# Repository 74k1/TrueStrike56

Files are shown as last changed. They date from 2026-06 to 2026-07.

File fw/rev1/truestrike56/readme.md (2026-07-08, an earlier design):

# TrueStrike56

TrueStrike56 is a columnar staggered unibody split Hall effect keyboard designed to maximize performance and minimize finger fatigue.

Hall effect part of this firmware code is a derivative work of Cipulot's code.
OLED display part of this firmware code is a derivative work of Dasky's code.

* Keyboard Maintainer: [byungyoonc](https://github.com/byungyoonc)
* Hardware Supported: RP2040 development boards with Pro Micro pin layout
* Hardware Availability: https://github.com/byungyoonc/TrueStrike56

Make example for this keyboard (after setting up your build environment):

    make truestrike56:default

Flashing example for this keyboard:

    make truestrike56:default:flash
    
    OR
    
    Copy the built `uf2` firmware file into `RPI-RP2` drive when the controller is in the bootloader mode

See the [build environment setup](https://docs.qmk.fm/#/getting_started_build_tools) and the [make instructions](https://docs.qmk.fm/#/getting_started_make_guide) for more information. Brand new to QMK? Start with our [Complete Newbs Guide](https://docs.qmk.fm/#/newbs).

## Bootloader

Enter the bootloader in 2 ways:

* **Physical reset button**: Quickly double-press the button on the back of the PCB
* **Keycode in layout**: Press the key mapped to `QK_BOOT` if it is available

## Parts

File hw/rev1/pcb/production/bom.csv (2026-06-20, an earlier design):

Designator | Footprint | Quantity | Value | LCSC Part #
C1, C10, C11, C12, C13, C14, C15, C16, C17, C18, C19, C2, C20, C21, C22, C23, C24, C25, C26, C27, C28, C29, C3, C30, C31, C32, C33, C34, C35, C36, C37, C38, C39, C4, C40, C41, C42, C43, C44, C45, C46, C47, C48, C49, C5, C50, C51, C52, C53, C54, C55, C56, C57, C58, C59, C6, C60, C61, C62, C63, C64, C65, C66, C67, C68, C69, C7, C70, C71, C72, C73, C74, C8, C9 | 0805 | 74 | 1uF | C28233
D1, D13, D14, D15, D16, D17, D18, D2, D3, D33, D34, D35, D36, D37, D38, D4, D45, D46, D47, D48, D49, D5, D50, D6 | SK6812MINI-E_nusumi | 24 | SK6812MINI-E | C5149201
D10, D11, D12, D19, D20, D21, D22, D23, D24, D25, D26, D27, D28, D29, D30, D31, D32, D39, D40, D41, D42, D43, D44, D51, D52, D53, D54, D55, D56, D7, D8, D9 | SK6812MINI-E_nusumi_Rotated | 32 | SK6812MINI-E | C5149201
S1, S10, S11, S12, S13, S14, S15, S16, S17, S18, S19, S2, S20, S21, S22, S23, S24, S25, S26, S27, S28, S29, S3, S30, S31, S32, S33, S34, S35, S36, S37, S38, S39, S4, S40, S41, S42, S43, S44, S45, S46, S47, S48, S49, S5, S50, S51, S54, S55, S56, S6, S7, S8, S9 | HE-Switch-1U | 54 | SLSS49E | C126669
S52, S53 | HE-Switch-1.5U | 2 | SLSS49E | C126669
SW1 | SW_Push_1P1T_XKB_TS-1187A | 1 | SW_Push | C318884
U10 | SOIC-16_3.9x9.9mm_P1.27mm | 1 | 4053 | C5647
U2, U3, U4, U5, U6, U7, U8 | SOIC-16_3.9x9.9mm_P1.27mm | 7 | 74HC4051 | C85220
U9 | SOIC-14_3.9x8.7mm_P1.27mm | 1 | 74AHCT125 | C155176

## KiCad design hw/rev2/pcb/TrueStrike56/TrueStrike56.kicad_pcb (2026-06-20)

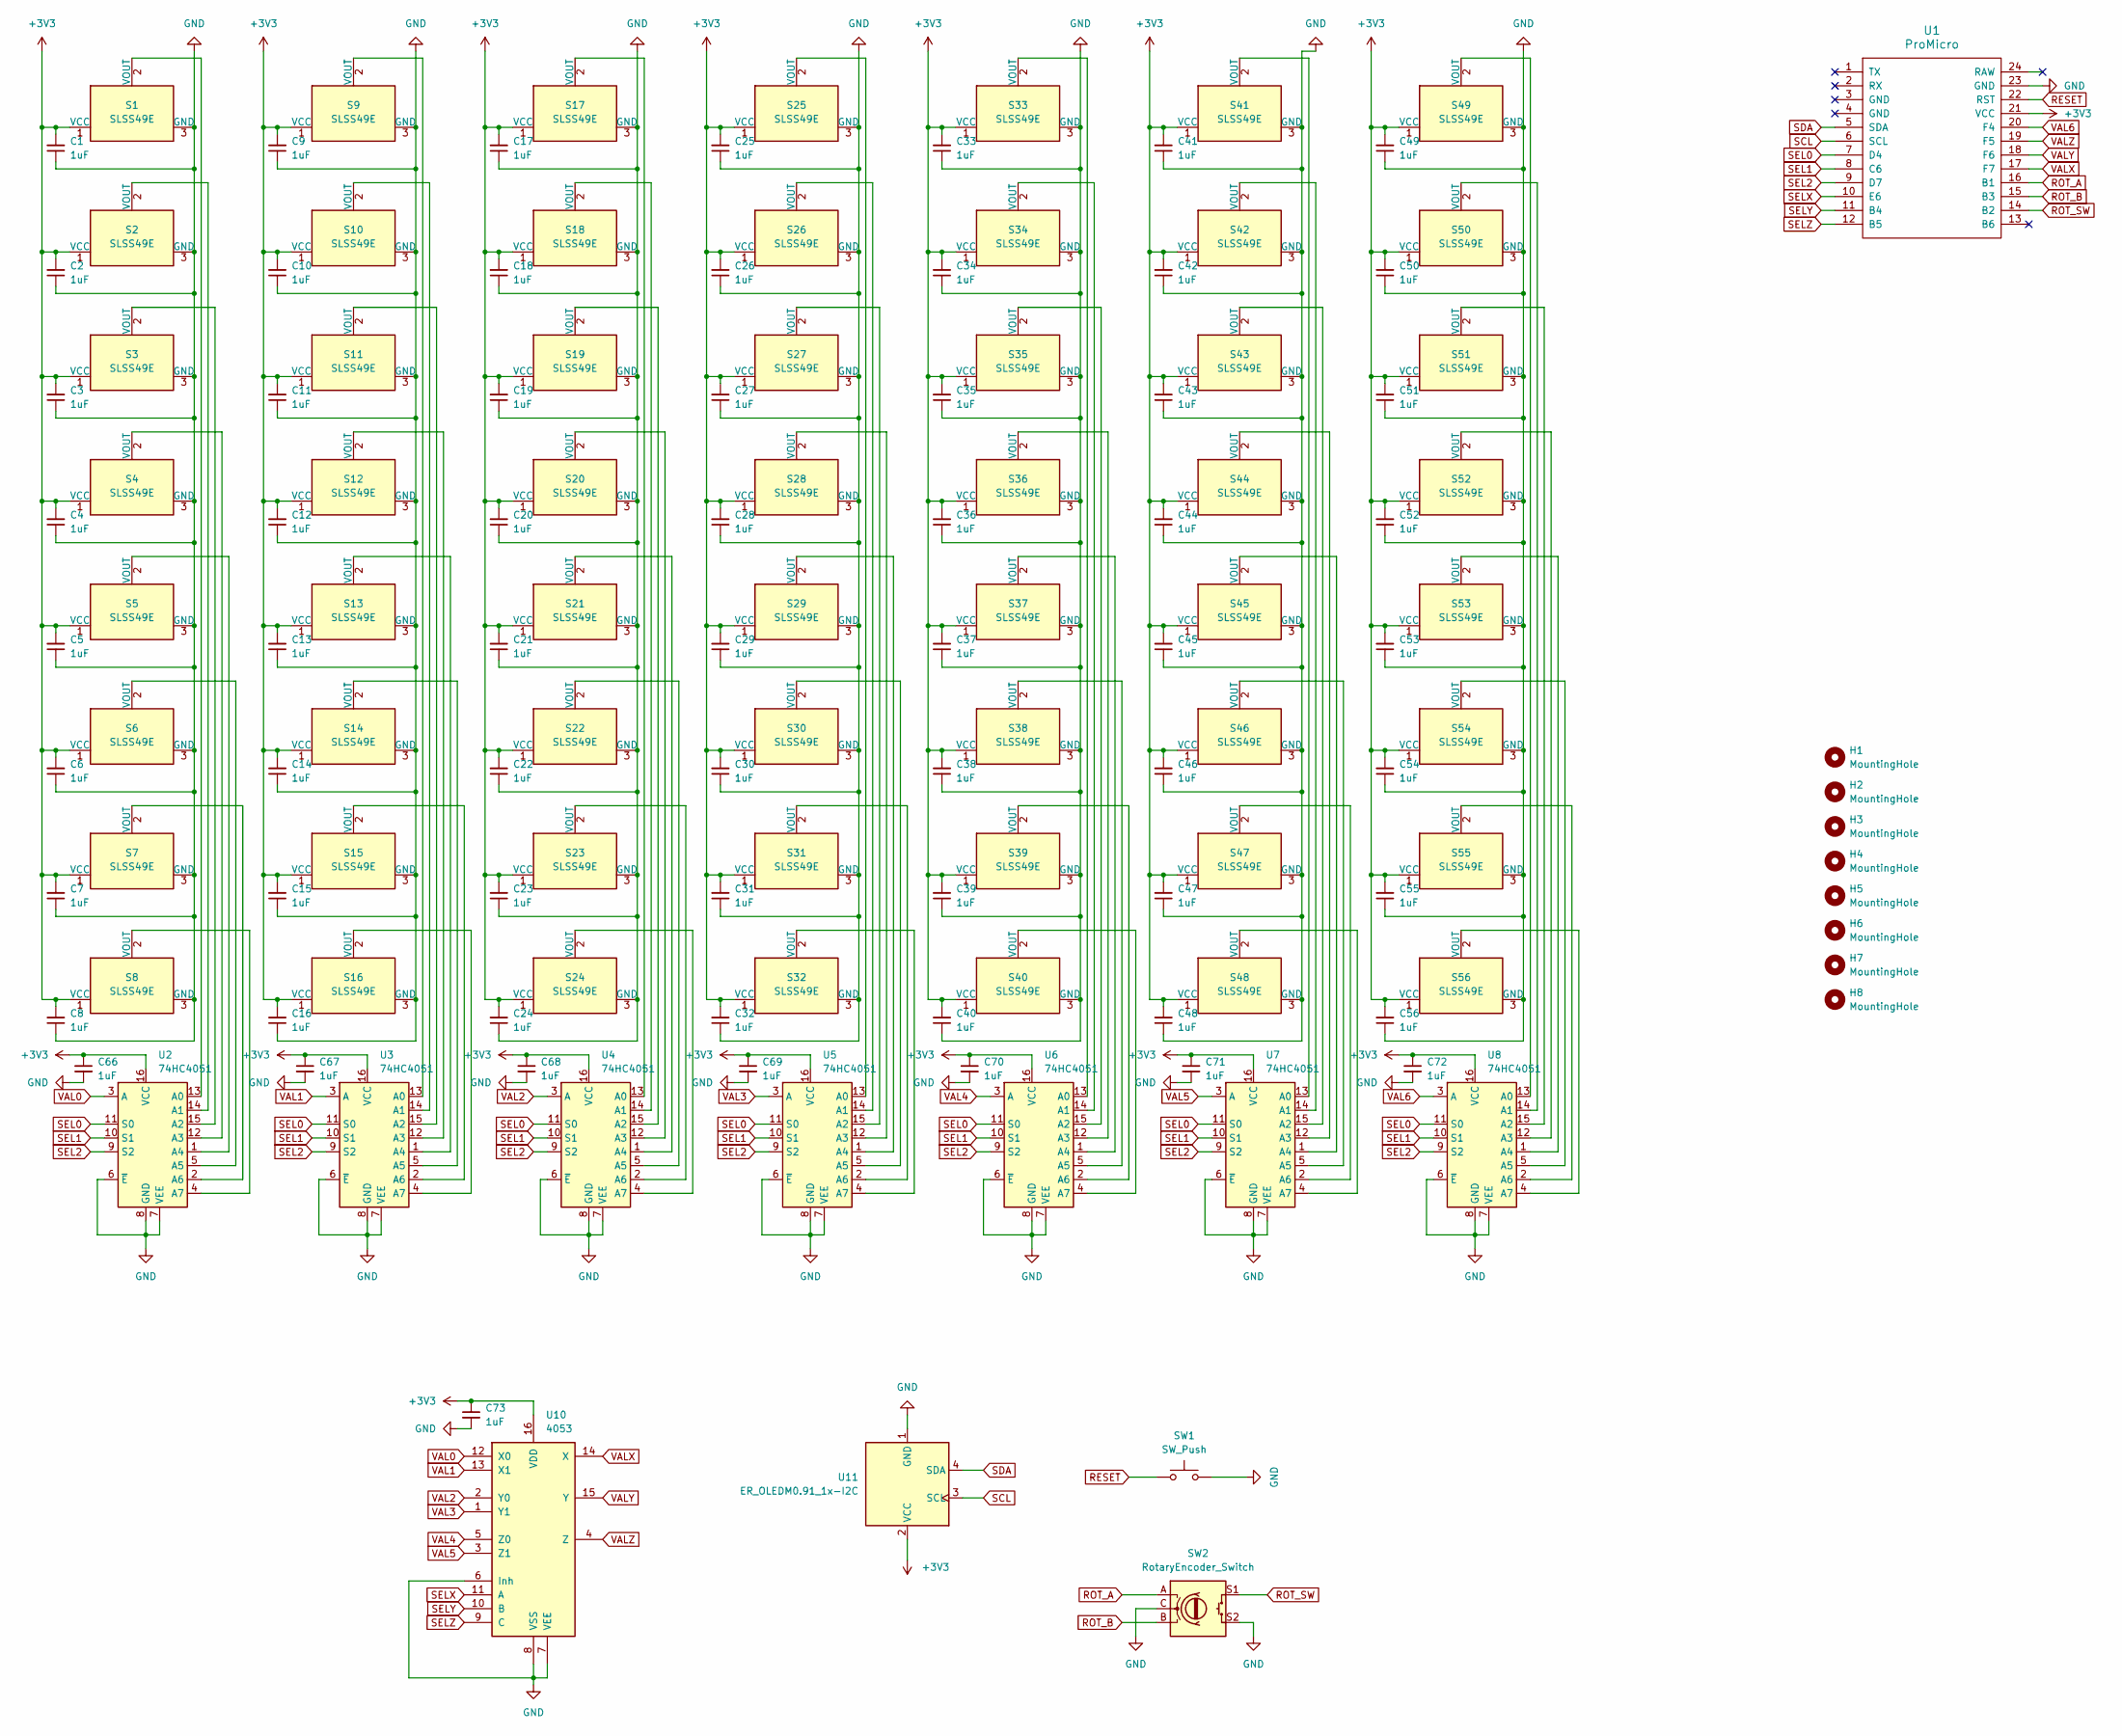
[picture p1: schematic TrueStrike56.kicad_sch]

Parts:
C1, C2, C3, C4, C5, C6, C7, C8, C9, C10, C11, C12, C13, C14, C15, C16, C17, C18, C19, C20, C21, C22, C23, C24, C25, C26, C27, C28, C29, C30, C31, C32, C33, C34, C35, C36, C37, C38, C39, C40, C41, C42, C43, C44, C45, C46, C47, C48, C49, C50, C51, C52, C53, C54, C55, C56, C66, C67, C68, C69, C70, C71, C72, C73: 1uF; C_0805_2012Metric_Pad1.18x1.45mm_HandSolder; LCSC Part # C28233
H1, H2, H3, H4, H5, H6, H7, H8: MountingHole; MountingHole_3.5mm
S1, S2, S3, S4, S5, S6, S7, S8, S9, S10, S11, S12, S13, S14, S15, S16, S17, S18, S19, S20, S21, S22, S23, S24, S25, S26, S27, S28, S29, S30, S31, S32, S33, S34, S35, S36, S37, S38, S39, S40, S41, S42, S43, S44, S45, S46, S47, S48, S49, S50, S51, S54, S55, S56: SLSS49E; HE-Switch-1U; LCSC Part # C126669
S52, S53: SLSS49E; HE-Switch-1.5U; LCSC Part # C126669
SW1: SW_Push; SW_Push_1P1T_XKB_TS-1187A; LCSC Part # C318884
SW2: RotaryEncoder_Switch; RollerEncoder_Panasonic_EVQWGD001
U1: ProMicro
U2, U3, U4, U5, U6, U7, U8: 74HC4051; SOIC-16_3.9x9.9mm_P1.27mm; LCSC Part # C85220
U10: 4053; SOIC-16_3.9x9.9mm_P1.27mm; LCSC Part # C5647
U11: ER_OLEDM0.91_1x-I2C

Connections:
+3V3: C1.2, C2.2, C3.2, C4.2, C5.2, C6.2, C7.2, C8.2, C9.2, C10.2, C11.2, C12.2, C13.2, C14.2, C15.2, C16.2, C17.2, C18.2, C19.2, C20.2, C21.2, C22.2, C23.2, C24.2, C25.2, C26.2, C27.2, C28.2, C29.2, C30.2, C31.2, C32.2, C33.2, C34.2, C35.2, C36.2, C37.2, C38.2, C39.2, C40.2, C41.2, C42.2, C43.2, C44.2, C45.2, C46.2, C47.2, C48.2, C49.2, C50.2, C51.2, C52.2, C53.2, C54.2, C55.2, C56.2, C66.1, C67.1, C68.1, C69.1, C70.1, C71.1, C72.1, C73.1, S1.1 (VCC), S2.1 (VCC), S3.1 (VCC), S4.1 (VCC), S5.1 (VCC), S6.1 (VCC), S7.1 (VCC), S8.1 (VCC), S9.1 (VCC), S10.1 (VCC), S11.1 (VCC), S12.1 (VCC), S13.1 (VCC), S14.1 (VCC), S15.1 (VCC), S16.1 (VCC), S17.1 (VCC), S18.1 (VCC), S19.1 (VCC), S20.1 (VCC), S21.1 (VCC), S22.1 (VCC), S23.1 (VCC), S24.1 (VCC), S25.1 (VCC), S26.1 (VCC), S27.1 (VCC), S28.1 (VCC), S29.1 (VCC), S30.1 (VCC), S31.1 (VCC), S32.1 (VCC), S33.1 (VCC), S34.1 (VCC), S35.1 (VCC), S36.1 (VCC), S37.1 (VCC), S38.1 (VCC), S39.1 (VCC), S40.1 (VCC), S41.1 (VCC), S42.1 (VCC), S43.1 (VCC), S44.1 (VCC), S45.1 (VCC), S46.1 (VCC), S47.1 (VCC), S48.1 (VCC), S49.1 (VCC), S50.1 (VCC), S51.1 (VCC), S52.1 (VCC), S53.1 (VCC), S54.1 (VCC), S55.1 (VCC), S56.1 (VCC), U1.21 (VCC), U2.16 (VCC), U3.16 (VCC), U4.16 (VCC), U5.16 (VCC), U6.16 (VCC), U7.16 (VCC), U8.16 (VCC), U10.16 (VDD), U11.2 (VCC)
GND: C1.1, C2.1, C3.1, C4.1, C5.1, C6.1, C7.1, C8.1, C9.1, C10.1, C11.1, C12.1, C13.1, C14.1, C15.1, C16.1, C17.1, C18.1, C19.1, C20.1, C21.1, C22.1, C23.1, C24.1, C25.1, C26.1, C27.1, C28.1, C29.1, C30.1, C31.1, C32.1, C33.1, C34.1, C35.1, C36.1, C37.1, C38.1, C39.1, C40.1, C41.1, C42.1, C43.1, C44.1, C45.1, C46.1, C47.1, C48.1, C49.1, C50.1, C51.1, C52.1, C53.1, C54.1, C55.1, C56.1, C66.2, C67.2, C68.2, C69.2, C70.2, C71.2, C72.2, C73.2, S1.3 (GND), S2.3 (GND), S3.3 (GND), S4.3 (GND), S5.3 (GND), S6.3 (GND), S7.3 (GND), S8.3 (GND), S9.3 (GND), S10.3 (GND), S11.3 (GND), S12.3 (GND), S13.3 (GND), S14.3 (GND), S15.3 (GND), S16.3 (GND), S17.3 (GND), S18.3 (GND), S19.3 (GND), S20.3 (GND), S21.3 (GND), S22.3 (GND), S23.3 (GND), S24.3 (GND), S25.3 (GND), S26.3 (GND), S27.3 (GND), S28.3 (GND), S29.3 (GND), S30.3 (GND), S31.3 (GND), S32.3 (GND), S33.3 (GND), S34.3 (GND), S35.3 (GND), S36.3 (GND), S37.3 (GND), S38.3 (GND), S39.3 (GND), S40.3 (GND), S41.3 (GND), S42.3 (GND), S43.3 (GND), S44.3 (GND), S45.3 (GND), S46.3 (GND), S47.3 (GND), S48.3 (GND), S49.3 (GND), S50.3 (GND), S51.3 (GND), S52.3 (GND), S53.3 (GND), S54.3 (GND), S55.3 (GND), S56.3 (GND), SW1.2, SW2.C, SW2.S2, U1.23 (GND), U2.6 (~E), U2.7 (VEE), U2.8 (GND), U3.6 (~E), U3.7 (VEE), U3.8 (GND), U4.6 (~E), U4.7 (VEE), U4.8 (GND), U5.6 (~E), U5.7 (VEE), U5.8 (GND), U6.6 (~E), U6.7 (VEE), U6.8 (GND), U7.6 (~E), U7.7 (VEE), U7.8 (GND), U8.6 (~E), U8.7 (VEE), U8.8 (GND), U10.6 (Inh), U10.7 (VEE), U10.8 (VSS), U11.1 (GND)
unnamed: S1.2 (VOUT), U2.13 (A0)
unnamed: S2.2 (VOUT), U2.14 (A1)
unnamed: S3.2 (VOUT), U2.15 (A2)
unnamed: S4.2 (VOUT), U2.12 (A3)
unnamed: S5.2 (VOUT), U2.1 (A4)
unnamed: S6.2 (VOUT), U2.5 (A5)
unnamed: S7.2 (VOUT), U2.2 (A6)
unnamed: S8.2 (VOUT), U2.4 (A7)
unnamed: S9.2 (VOUT), U3.13 (A0)
unnamed: S10.2 (VOUT), U3.14 (A1)
unnamed: S11.2 (VOUT), U3.15 (A2)
unnamed: S12.2 (VOUT), U3.12 (A3)
unnamed: S13.2 (VOUT), U3.1 (A4)
unnamed: S14.2 (VOUT), U3.5 (A5)
unnamed: S15.2 (VOUT), U3.2 (A6)
unnamed: S16.2 (VOUT), U3.4 (A7)
unnamed: S17.2 (VOUT), U4.13 (A0)
unnamed: S18.2 (VOUT), U4.14 (A1)
unnamed: S19.2 (VOUT), U4.15 (A2)
unnamed: S20.2 (VOUT), U4.12 (A3)
unnamed: S21.2 (VOUT), U4.1 (A4)
unnamed: S22.2 (VOUT), U4.5 (A5)
unnamed: S23.2 (VOUT), U4.2 (A6)
unnamed: S24.2 (VOUT), U4.4 (A7)
unnamed: S25.2 (VOUT), U5.13 (A0)
unnamed: S26.2 (VOUT), U5.14 (A1)
unnamed: S27.2 (VOUT), U5.15 (A2)
unnamed: S28.2 (VOUT), U5.12 (A3)
unnamed: S29.2 (VOUT), U5.1 (A4)
unnamed: S30.2 (VOUT), U5.5 (A5)
unnamed: S31.2 (VOUT), U5.2 (A6)
unnamed: S32.2 (VOUT), U5.4 (A7)
unnamed: S33.2 (VOUT), U6.13 (A0)
unnamed: S34.2 (VOUT), U6.14 (A1)
unnamed: S35.2 (VOUT), U6.15 (A2)
unnamed: S36.2 (VOUT), U6.12 (A3)
unnamed: S37.2 (VOUT), U6.1 (A4)
unnamed: S38.2 (VOUT), U6.5 (A5)
unnamed: S39.2 (VOUT), U6.2 (A6)
unnamed: S40.2 (VOUT), U6.4 (A7)
unnamed: S41.2 (VOUT), U7.13 (A0)
unnamed: S42.2 (VOUT), U7.14 (A1)
unnamed: S43.2 (VOUT), U7.15 (A2)
unnamed: S44.2 (VOUT), U7.12 (A3)
unnamed: S45.2 (VOUT), U7.1 (A4)
unnamed: S46.2 (VOUT), U7.5 (A5)
unnamed: S47.2 (VOUT), U7.2 (A6)
unnamed: S48.2 (VOUT), U7.4 (A7)
unnamed: S49.2 (VOUT), U8.13 (A0)
unnamed: S50.2 (VOUT), U8.14 (A1)
unnamed: S51.2 (VOUT), U8.15 (A2)
unnamed: S52.2 (VOUT), U8.12 (A3)
unnamed: S53.2 (VOUT), U8.1 (A4)
unnamed: S54.2 (VOUT), U8.5 (A5)
unnamed: S55.2 (VOUT), U8.2 (A6)
unnamed: S56.2 (VOUT), U8.4 (A7)
RESET: SW1.1, U1.22 (RST)
ROT_A: SW2.A, U1.16 (B1)
ROT_B: SW2.B, U1.15 (B3)
ROT_SW: SW2.S1, U1.14 (B2)
SCL: U1.6 (SCL), U11.3 (SCL)
SDA: U1.5 (SDA), U11.4 (SDA)
SEL0: U1.7 (D4), U2.11 (S0), U3.11 (S0), U4.11 (S0), U5.11 (S0), U6.11 (S0), U7.11 (S0), U8.11 (S0)
SEL1: U1.8 (C6), U2.10 (S1), U3.10 (S1), U4.10 (S1), U5.10 (S1), U6.10 (S1), U7.10 (S1), U8.10 (S1)
SEL2: U1.9 (D7), U2.9 (S2), U3.9 (S2), U4.9 (S2), U5.9 (S2), U6.9 (S2), U7.9 (S2), U8.9 (S2)
SELX: U1.10 (E6), U10.11 (A)
SELY: U1.11 (B4), U10.10 (B)
SELZ: U1.12 (B5), U10.9 (C)
VAL0: U2.3 (A), U10.12 (X0)
VAL1: U3.3 (A), U10.13 (X1)
VAL2: U4.3 (A), U10.2 (Y0)
VAL3: U5.3 (A), U10.1 (Y1)
VAL4: U6.3 (A), U10.5 (Z0)
VAL5: U7.3 (A), U10.3 (Z1)
VAL6: U1.20 (F4), U8.3 (A)
VALX: U1.17 (F7), U10.14 (X)
VALY: U1.18 (F6), U10.15 (Y)
VALZ: U1.19 (F5), U10.4 (Z)

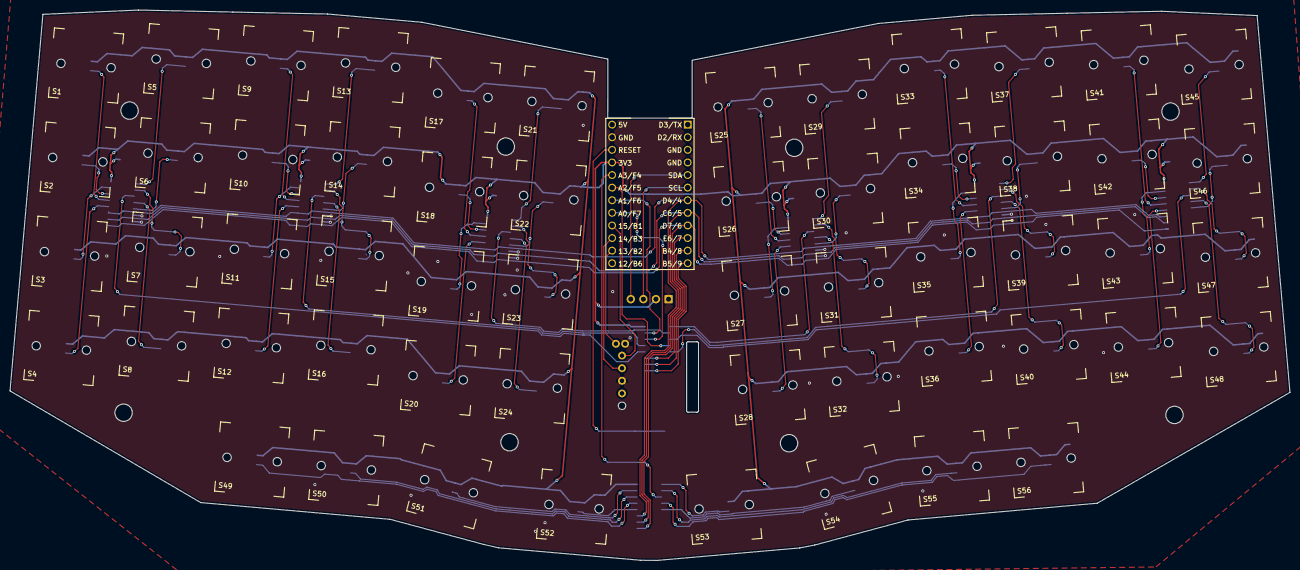
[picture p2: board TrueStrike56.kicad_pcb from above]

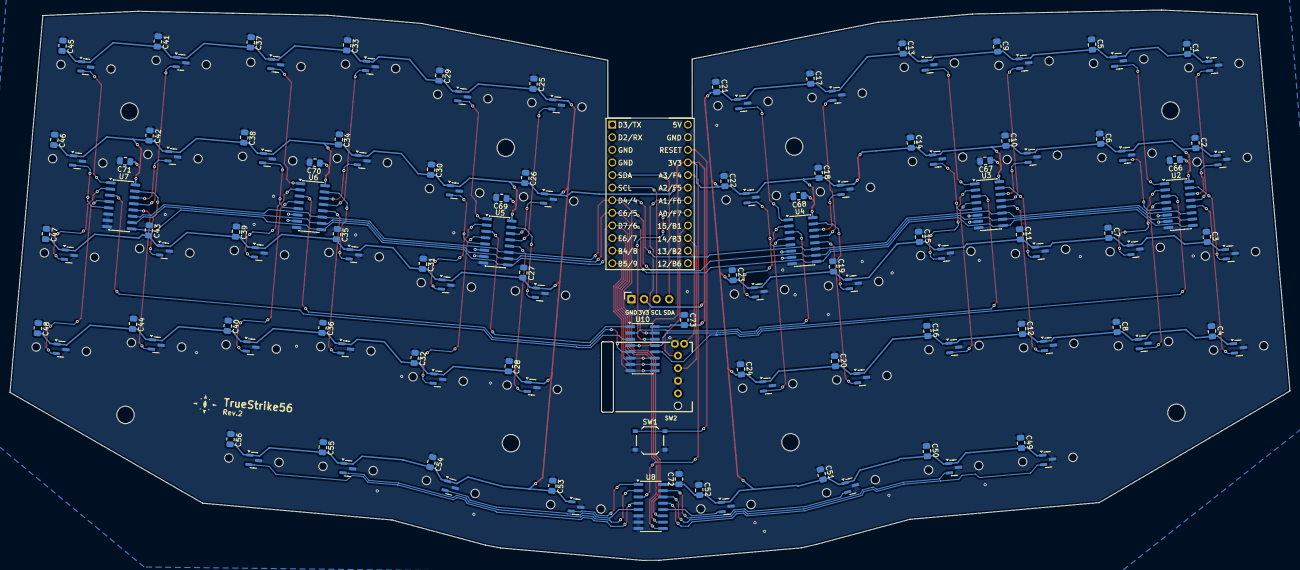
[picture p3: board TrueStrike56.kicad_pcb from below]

Board: 2 copper layers, 258.0 x 110.9 mm, 140 parts (130 on the bottom side), 80 nets.

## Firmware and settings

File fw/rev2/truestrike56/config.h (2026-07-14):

/* Copyright 2024 byungyoonc
 *
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
 * You should have received a copy of the GNU General Public License
 * along with this program.  If not, see <http://www.gnu.org/licenses/>.
 */

#pragma once

#define MATRIX_ROWS 4
#define MATRIX_COLS 16

#define MATRIX_ROW_PINS \
    { GP26, GP27, GP28, GP29 }

#define ROWS_PER_COL \
    { 4, 4, 4, 4, 4, 4, 4, 4, 3, 3, 3, 3, 3, 3, 3, 3 }

#define AMUX_MAX_COLS_COUNT 16

#define AMUX_SEL_PINS \
    { GP4, GP5, GP6, GP7, GP8, GP9 }
#define AMUX_COL_CHANNELS \
    { 0, 1, 2, 3, 4, 5, 6, 7, 56, 57, 58, 59, 60, 61, 62, 63 }

#define ENCODER_A_PINS { GP22 }
#define ENCODER_B_PINS { GP20 }

#define DIRECT_SW_ROWS { 3 }
#define DIRECT_SW_COLS { 8 }
#define ENCODER_SW_PINS { GP23 }

#define REVERSE_POLARITY

#define ADC_RESOLUTION 10

#define DEFAULT_ACTUATION_MODE 1
#define DEFAULT_MODE_0_ACTUATION_LEVEL 350
#define DEFAULT_MODE_0_RELEASE_LEVEL 400
#define DEFAULT_MODE_1_INITIAL_DEADZONE_OFFSET DEFAULT_MODE_0_ACTUATION_LEVEL
#define DEFAULT_MODE_1_ACTUATION_OFFSET 30
#define DEFAULT_MODE_1_RELEASE_OFFSET 30
#define DEFAULT_EXTREMUM 1023
#define NOISE_CEILING_THRESHOLD 50
#define BOTTOMING_CALIBRATION_THRESHOLD 50
#define DEFAULT_NOISE_CEILING_SAMPLING_COUNT 30
#define DEFAULT_BOTTOMING_READING 0
#define DEFAULT_CALIBRATION_STARTER true

#define EECONFIG_KB_DATA_SIZE 137

#define DEBUG_MATRIX_SCAN_RATE

#define QUANTUM_PAINTER_DISPLAY_TIMEOUT 60000

#define RP2040_BOOTLOADER_DOUBLE_TAP_RESET

#define WEAR_LEVELING_LOGICAL_SIZE 4096
#define WEAR_LEVELING_BACKING_SIZE 32768

#define I2C_DRIVER I2CD1
#define I2C1_CLOCK_SPEED 400000
#define I2C1_SDA_PIN GP2
#define I2C1_SCL_PIN GP3

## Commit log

2026-06-20 Move existing hardware files under rev1
    [TrueStrike56-B_Cu.gbl, TrueStrike56-B_Mask.gbs, TrueStrike56-B_Paste.gbp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]
2026-06-20 Add rev2 hw project
    [TrueStrike56.kicad_pcb, TrueStrike56.kicad_sch]
2026-06-20 Add mounting holes to PCB
    [TrueStrike56.kicad_pcb, TrueStrike56.kicad_sch]
2026-07-01 feat(hw/rev2): init case
2026-07-10 feat(fw/rev2): correct dip switch matrix polarity
2026-07-13 Fix dip switch matrix scan
2026-07-14 fix(fw/rev2): re-init display on usb resume after suspend
    Full qp_init + qp_clear + qp_flush in suspend_wakeup_init_kb
    so the SH1106's I2C comms and surface dirty-state reset to
    a clean baseline after USB resume, preventing persistent
    full-frame flushes that crush the matrix scan rate.
2026-07-26 feat(hw/rev2): add build guide
    [TrueStrike_Case_bottom_plate.obj, TrueStrike_Case_bottom_plate.step, TrueStrike_Case_top_plate.obj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]
2026-09-23 feat(docs): add gallery
    [TrueStrike_bottom_plate.obj, TrueStrike_bottom_plate.step, TrueStrike_top_plate.obj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]

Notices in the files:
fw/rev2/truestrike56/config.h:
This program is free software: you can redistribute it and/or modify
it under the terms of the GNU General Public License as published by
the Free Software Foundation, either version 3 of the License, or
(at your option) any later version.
